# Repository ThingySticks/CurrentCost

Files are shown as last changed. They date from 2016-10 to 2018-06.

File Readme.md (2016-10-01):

Connect Photon/Electron to a CurrentCost unit via the RJ45 interface underneat and replace the NetSmart

Pin outs:

1 Vcc supply
4 GND
7 EnviR Unit Rx Data
8 EnviR Unit Tx Data

Data:

<msg>          
   <src>CC128-v0.11</src> 
   <dsb>00089</dsb>     
   <time>13:02:39</time>     
   <tmpr>18.7</tmpr>        
   <sensor>1</sensor>     
   <id>01234</id>                
   <type>1</type>              
   <ch1>
      <watts>00345</watts>
   </ch1>
   <ch2>
      <watts>02151</watts>
   </ch2>
   <ch3>
      <watts>00000</watts>
   </ch3>
</msg>

Expected Serial interface:

 baudrate: 57600,
  dataBits: 8,
  parity: 'none',
  stopBits: 1

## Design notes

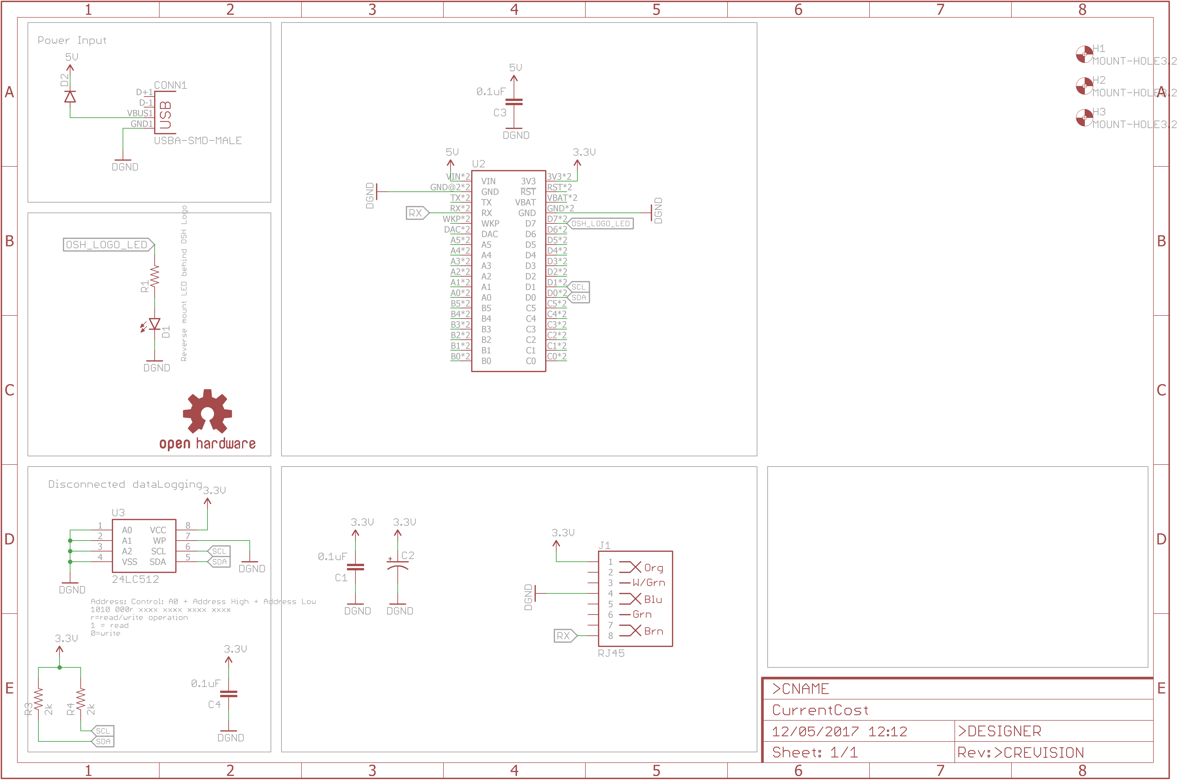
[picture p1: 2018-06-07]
Electron/V1/Images/Schematic.png

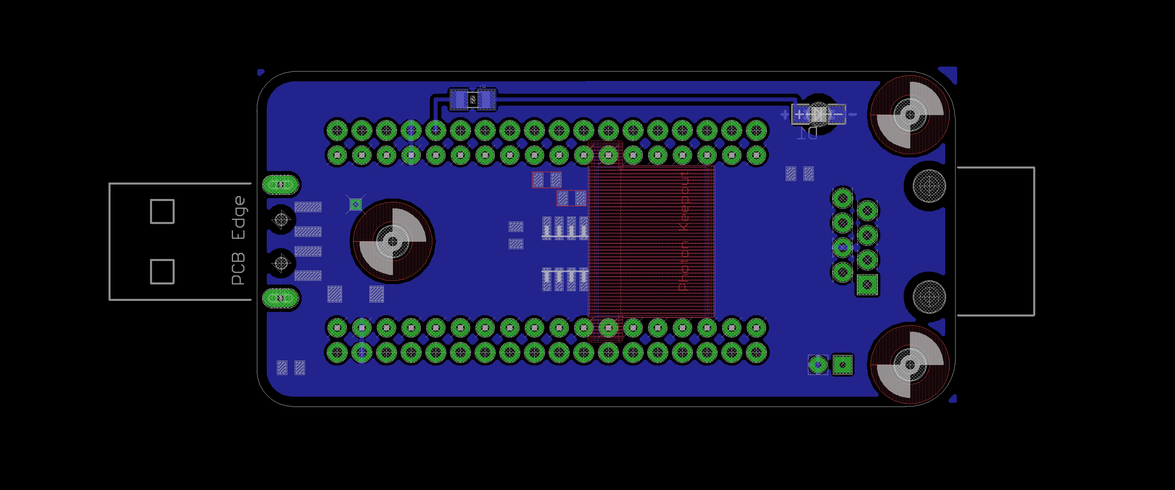
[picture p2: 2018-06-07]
Electron/V1/Images/PcbBottom.png

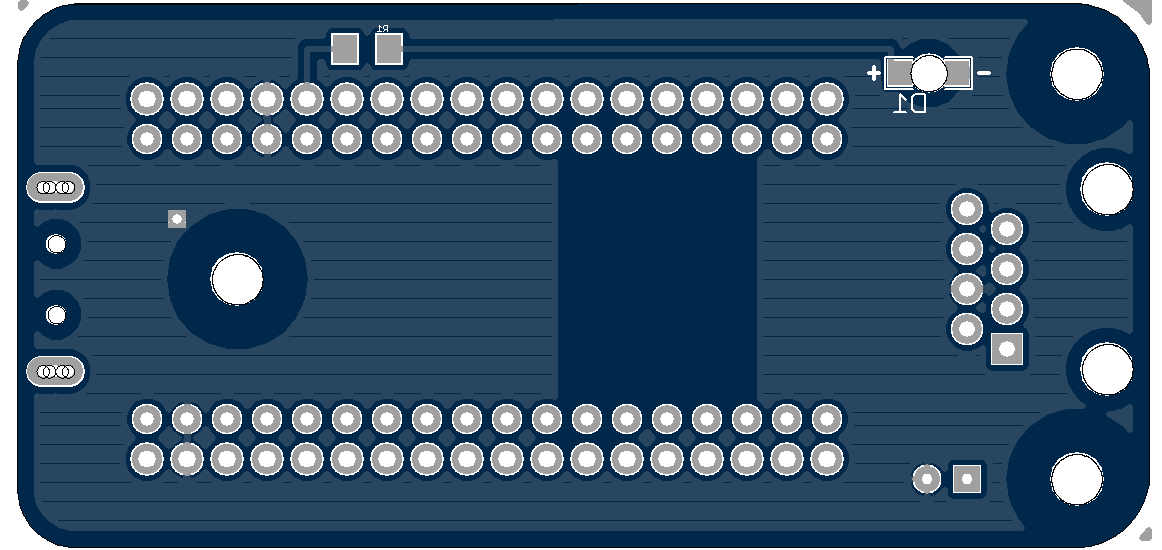
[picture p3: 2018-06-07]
Media/bottom.png

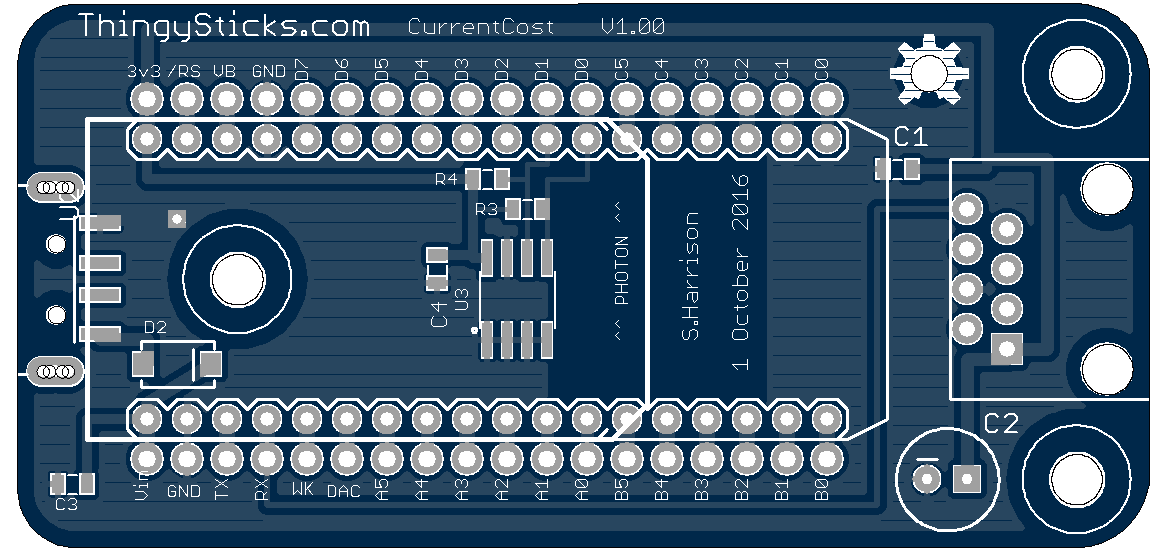
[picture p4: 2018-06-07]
Media/top.png

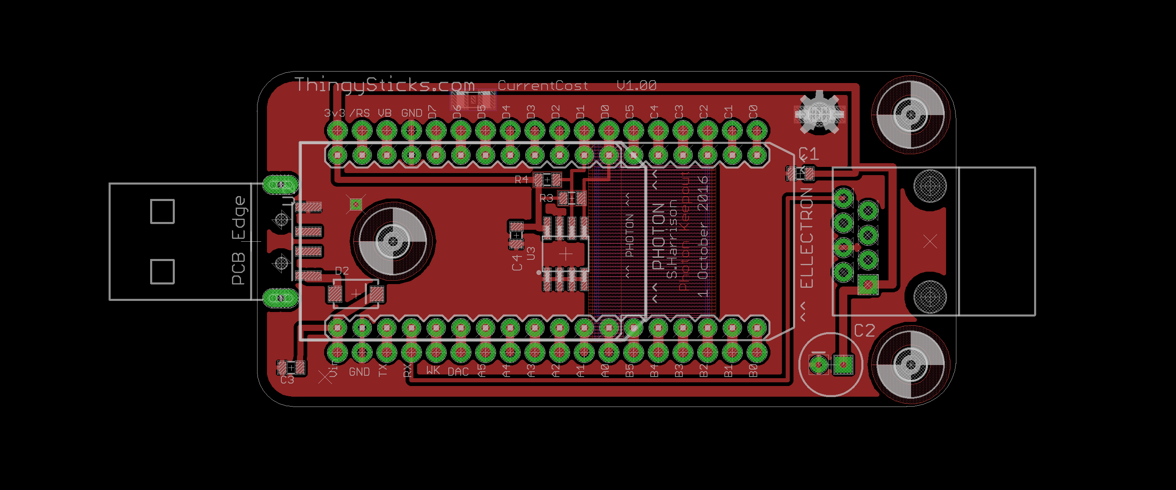
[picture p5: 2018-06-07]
Electron/V1/Images/PcbTop.png

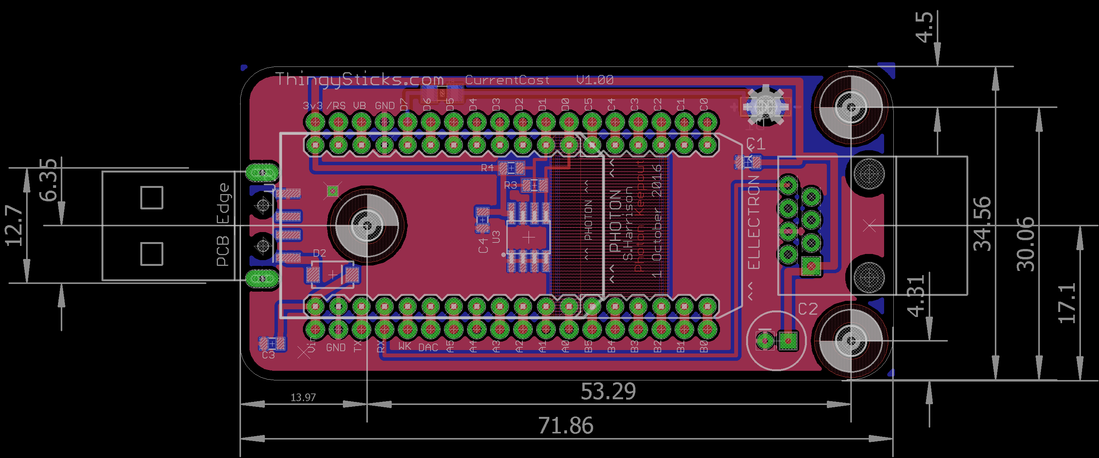
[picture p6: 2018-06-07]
Electron/V1/Images/PcbAll.png

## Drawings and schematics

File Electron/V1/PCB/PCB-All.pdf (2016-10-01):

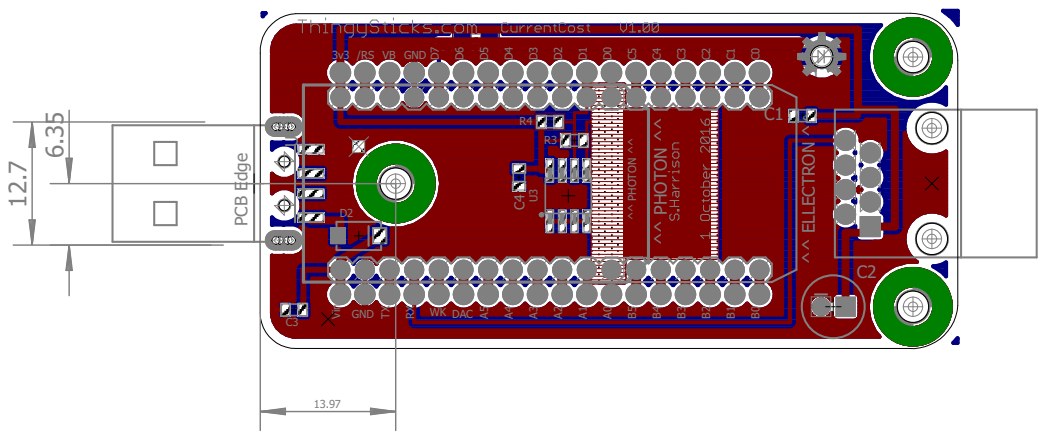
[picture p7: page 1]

1D 1R Photon Keepout PCB Edge ^^ PHOTON ^U^ 2 3v3 /RS VB GND D7 VinGND TXRXWK DAC A5A4A3A2A1A0B5B4B3B2B1B0 D6D5D4D3D2D1D0C5C4C3C2C1C0 D2 C3 U3 C4 R3 R4 C1 C2 ^^ PHOTON ^^ ^^ ELLECTRON ^^ 12.76.35 13.97

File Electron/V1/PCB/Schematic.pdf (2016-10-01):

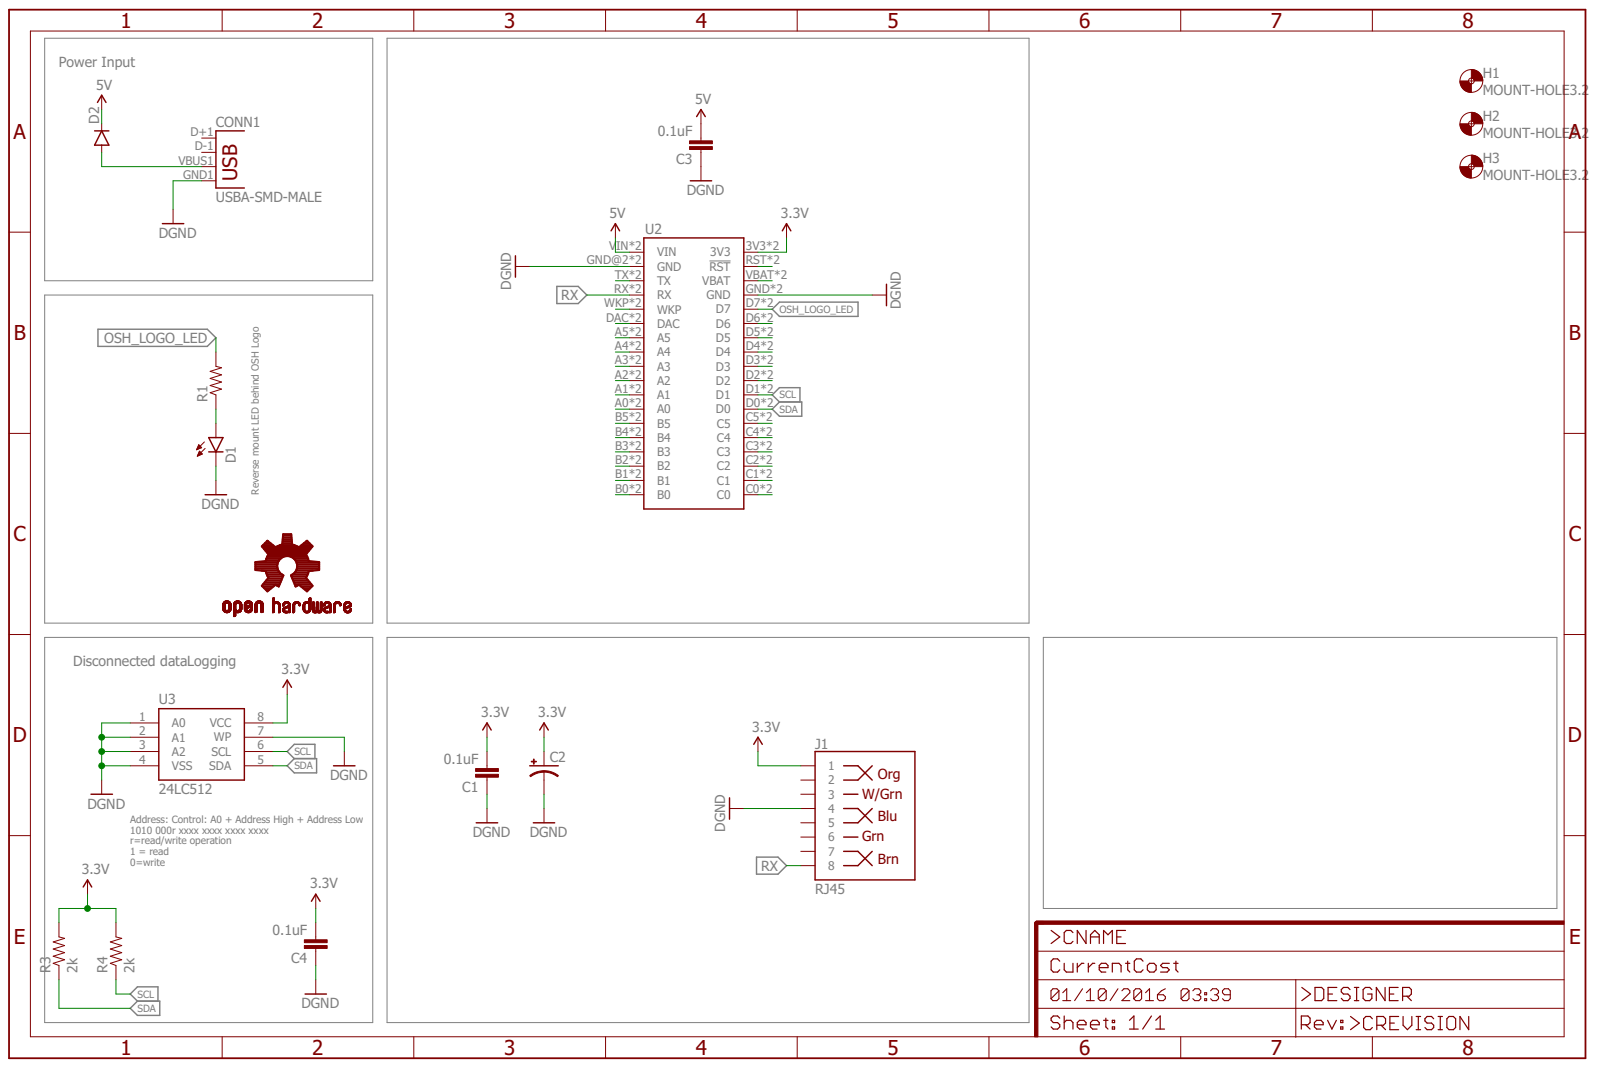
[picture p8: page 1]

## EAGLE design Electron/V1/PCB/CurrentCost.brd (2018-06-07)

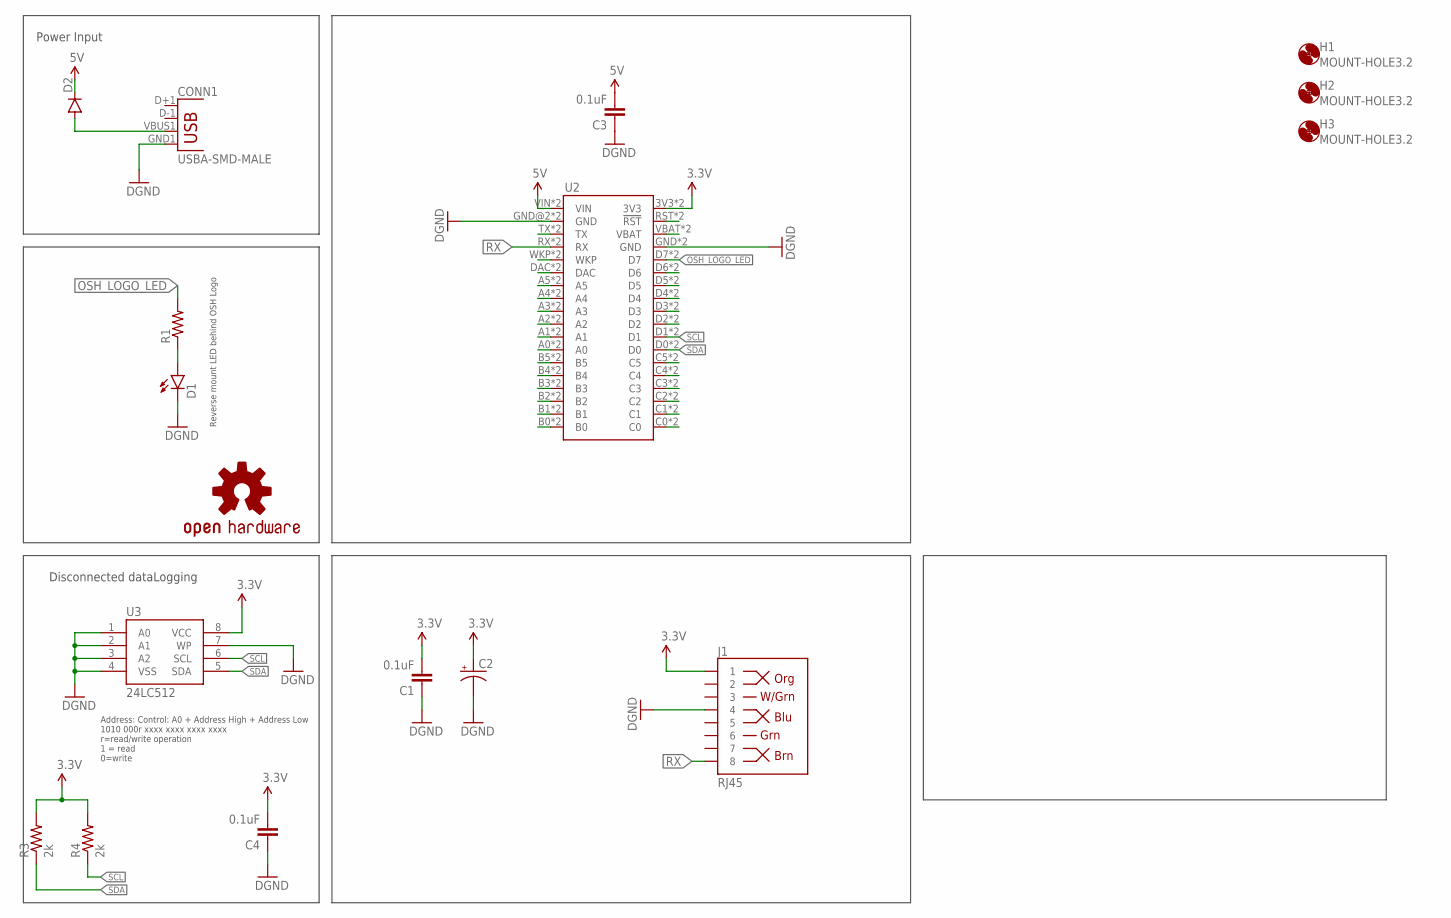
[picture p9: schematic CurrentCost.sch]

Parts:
C1, C3, C4: 0.1uF; 0805
C2: CAP_POLPTH1; CPOL-RADIAL-100UF-25V
CONN1: USBA-SMD-MALE; USB-A-SMT-MALE
D1: LED1206-BOTTOM; LED-1206-BOTTOM
D2: DIODESMA; SMA-DIODE
H1, H2, H3: MOUNT-HOLE3.2; 3,2
J1: RJ45; RJ45-8; FARNELL 1524544
LOGO1: OSHW-LOGOM; OSHW-LOGO-M
R1: RESISTOR1206; 1206
R3, R4: 2k; 0805
U2: ELECTRONDUALNAMED; ELECTRON_SIMPLE_SILK_NAMES_DUAL
U3: 24LC512; SO08; FARNELL 1801220

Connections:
3.3V: C1.2, C2.1 (+), C4.2, J1.1, R3.2, R4.2, U2.3V3, U2.3V3_1 (3V3), U3.8 (VCC)
5V: C3.2, D2.C, U2.VIN, U2.VIN_1B (VIN)
DQ: U2.A0, U2.A0_1 (A0)
GND: C1.1, C2.2 (-), C3.1, C4.1, CONN1.GND1 (GND), D1.C, J1.4, U2.GND, U2.GND@2 (GND), U2.GND_1 (GND), U2.GND_1B (GND), U3.1 (A0), U3.2 (A1), U3.3 (A2), U3.4 (VSS), U3.7 (WP)
MISO: U2.A4, U2.A4_1 (A4)
MOSI: U2.A5, U2.A5_1 (A5)
unnamed: CONN1.VBUS1 (VBUS), D2.A
unnamed: U2.A1, U2.A1_1 (A1)
unnamed: U2.D2, U2.D2_1 (D2)
unnamed: U2.VBAT, U2.VBATT_1 (VBAT)
unnamed: U2.RST (!RST), U2.RST_1 (!RST)
unnamed: U2.D3, U2.D3_1 (D3)
unnamed: U2.D6, U2.D6_1 (D6)
unnamed: U2.D5, U2.D5_1 (D5)
unnamed: D1.A, R1.1
unnamed: U2.C1, U2.C1_1 (C1)
unnamed: U2.C5, U2.C5_1 (C5)
unnamed: U2.C4, U2.C4_1 (C4)
unnamed: U2.C3, U2.C3_1 (C3)
unnamed: U2.C2, U2.C2_1 (C2)
unnamed: U2.C0, U2.C0_1 (C0)
unnamed: U2.D4, U2.D4_1 (D4)
unnamed: U2.B0, U2.B0_1 (B0)
unnamed: U2.B1, U2.B1_1 (B1)
unnamed: U2.B2, U2.B2_1 (B2)
unnamed: U2.B3, U2.B3_1 (B3)
unnamed: U2.B4, U2.B4_1 (B4)
unnamed: U2.B5, U2.B5_1 (B5)
unnamed: U2.WKP, U2.WKP_1 (WKP)
unnamed: U2.TX, U2.TX_1 (TX)
OSH_LOGO_LED: R1.2, U2.D7, U2.D7_1 (D7)
RX: J1.8, U2.RX, U2.RX_1 (RX)
SCK: U2.A3, U2.A3_1 (A3)
SCL: R4.1, U2.D1, U2.D1_1 (D1), U3.6 (SCL)
SDA: R3.1, U2.D0, U2.D0_1 (D0), U3.5 (SDA)
SS: U2.A2, U2.A2_1 (A2)
VIN_MONITOR: U2.DAC, U2.DAC_1 (DAC)

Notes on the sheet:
Disconnected dataLogging
Power Input
Reverse mount LED behind OSH Logo
Address: Control: A0 + Address High + Address Low
1010 000r xxxx xxxx xxxx xxxx r=read/write operation 1 = read 0=write

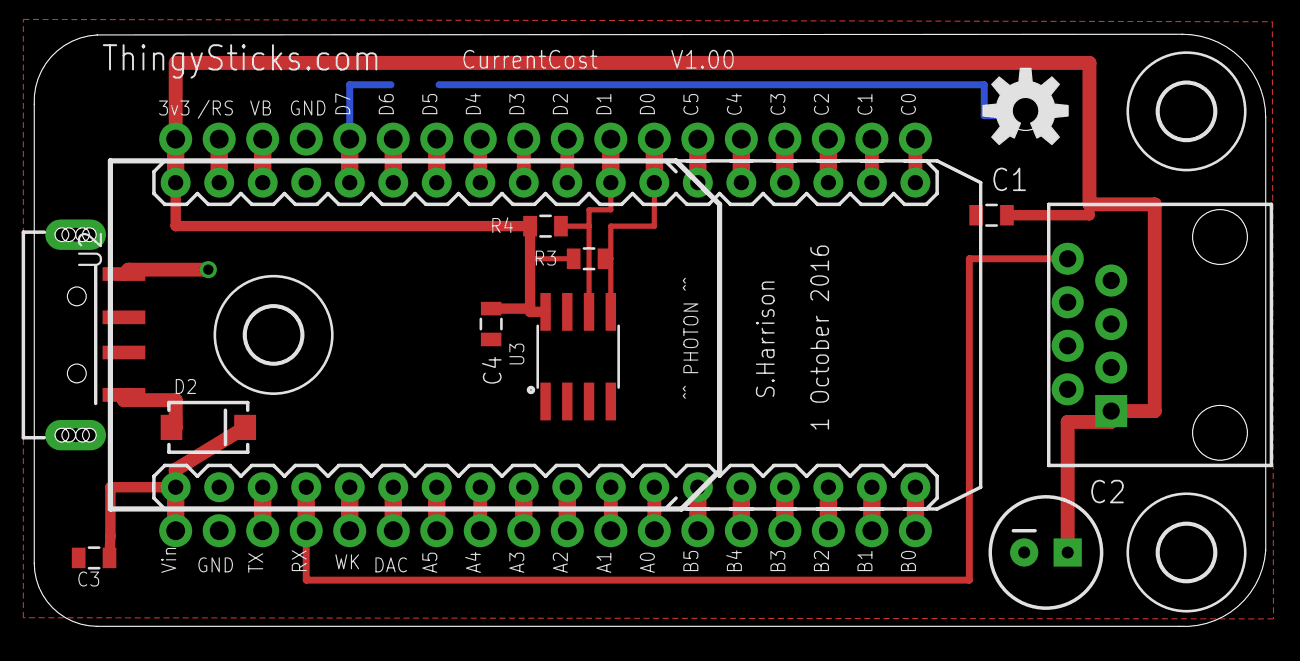
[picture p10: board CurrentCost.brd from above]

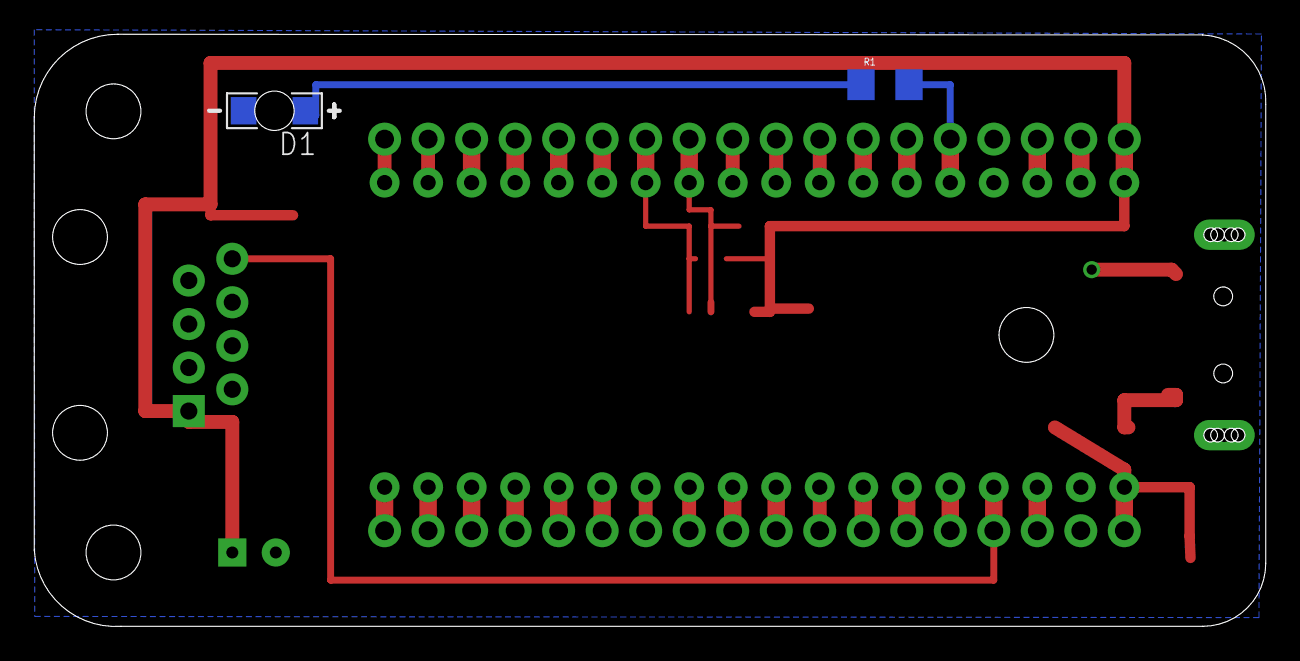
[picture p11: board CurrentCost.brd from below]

Board: 2 copper layers, 71.9 x 34.6 mm, 17 parts (2 on the bottom side), 37 nets.

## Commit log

2016-10-01 Initial version as send to DirtyPCBs.
    [CurrentCost.brd, CurrentCost.sch]
2018-06-07 Improved measurements and added value for RJ45
    [CurrentCost.brd, CurrentCost.sch]
2018-06-07 Image exports from the PCB.

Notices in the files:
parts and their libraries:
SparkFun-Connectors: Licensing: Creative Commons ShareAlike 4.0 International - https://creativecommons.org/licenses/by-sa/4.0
